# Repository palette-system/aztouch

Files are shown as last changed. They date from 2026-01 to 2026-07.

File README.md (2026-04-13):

# AZTOUCH (ミニトラックパッド)

<table><tr><td>
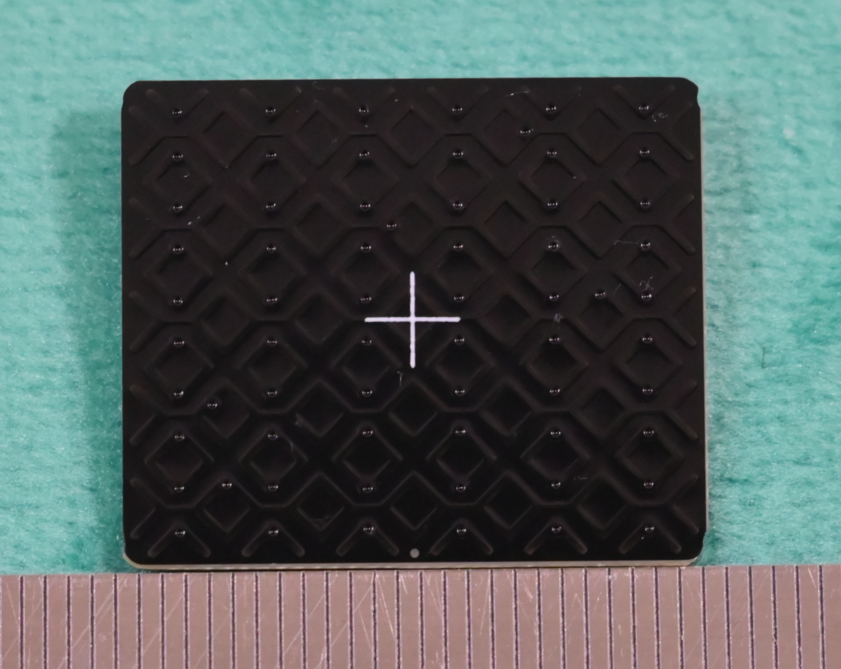
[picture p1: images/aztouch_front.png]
<br>
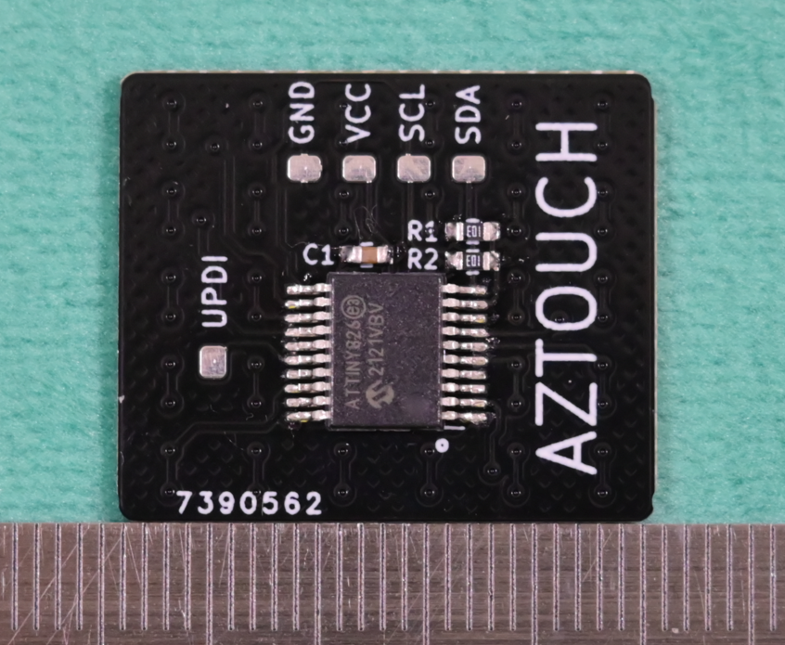
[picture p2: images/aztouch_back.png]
<br>
</td><td>
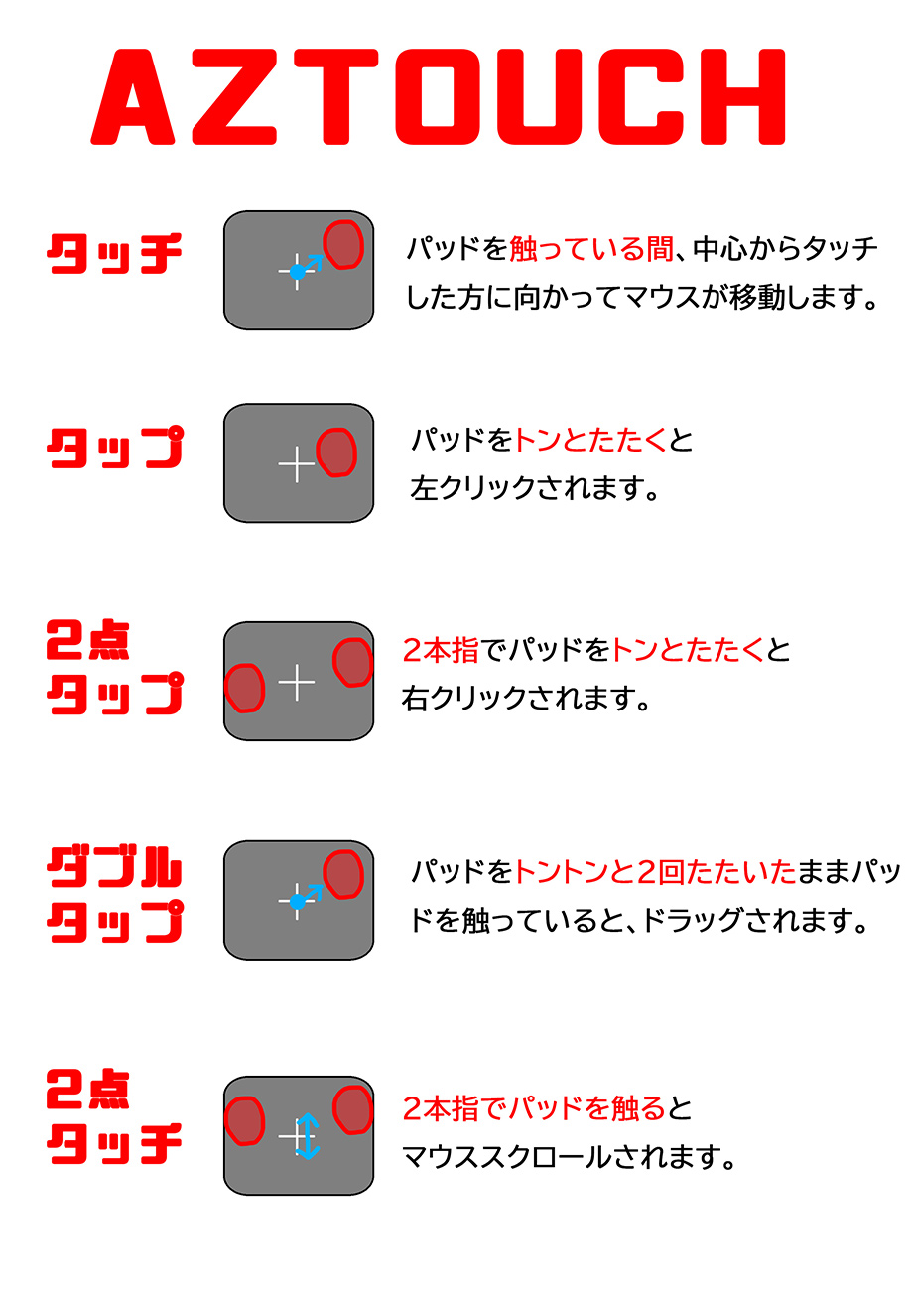
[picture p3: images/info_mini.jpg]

</td></tr></table>

<br><br>

## 接続方法

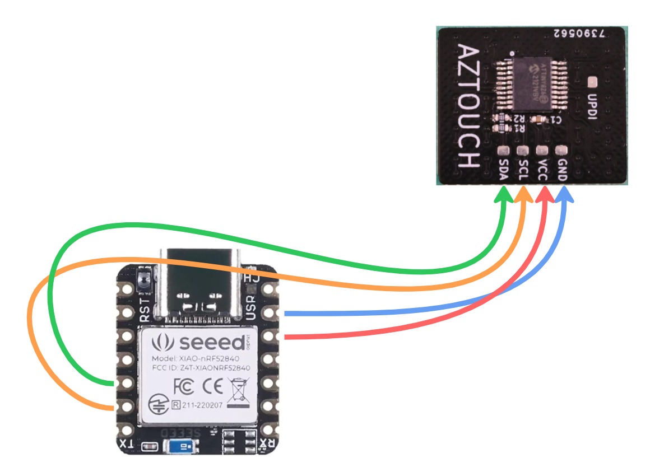
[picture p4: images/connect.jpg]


<br><br>

## 基本情報

<br>

電圧： 3V～5V<br>
消費電力： 1.7mA～2mA<br>
サイズ： 幅：25mm 高さ：21mm 厚さ：1mm<br>
I2Cアドレス：0x0A(固定)<br>

<br>
※ 電池駆動推薦、電源が安定しないと動作が不安定になる場合があります。<br>

<br><br>

## コマンド

<table>
  <tr>
    <th>コマンド</th>
    <th>内容</th>
  </tr>
  <tr>
    <td>0x30</td>
    <td>
    <b>設定値要求</b><br>
    このコマンドを送った次にデータリクエストが来た時に、1度だけ下記の7バイトのレスポンスになる。<br>
    [<br>
    　0x23(固定),<br>
    　マウススピード設定(0x00 ～ 0x04),<br>
    　drag_touch_time_max,<br>
    　drag_interval_time_max,<br>
    　tap_touch_time_max,<br>
    　move_touch_time_start,<br>
    　read_wait_time<br>
    ]<br>
    <br>
    コマンド例：[0x30]
    </td>
  </tr>
  <tr>
    <td>0x40</td>
    <td>
    <b>マウスのスピード設定</b><br>
    次に送られてきたバイトで移動速度を設定。<br>
    0x00 ～ 0x04 の間で設定可能<br>
    デフォルト値：0x02<br>
    <br>
    コマンド例：[0x40, 0x01]
    </td>
  </tr>
  <tr>
    <td>0x41</td>
    <td>
    <b>ドラッグ1回目のタッチの最大時間(n / 5ms)</b><br>
    次に送られてきたバイトで <b>drag_touch_time_max</b> の値を設定。<br>
    ※ 1=5ミリ秒、デフォルト値：0x64(500ミリ秒)<br>
    <br>
    コマンド例：[0x41, 0x64]
    </td>
  </tr>
  <tr>
    <td>0x42</td>
    <td>
    <b>ドラッグ2回目のタッチまでの最大時間(n / 5ms)</b><br>
    次に送られてきたバイトで <b>drag_interval_time_max</b> の値を設定。<br>
    ※ 1=5ミリ秒、デフォルト値：0x28(200ミリ秒)<br>
    <br>
    コマンド例：[0x42, 0x28]
    </td>
  </tr>
  <tr>
    <td>0x43</td>
    <td>
    <b>タップのタッチの最大時間(n / 5ms)</b><br>
    次に送られてきたバイトで <b>tap_touch_time_max</b> の値を設定。<br>
    ※ 1=5ミリ秒、デフォルト値：0x14(100ミリ秒)<br>
    <br>
    コマンド例：[0x43, 0x14]
    </td>
  </tr>
  <tr>
    <td>0x44</td>
    <td>
    <b>移動開始するまでの時間(n / 5ms)</b><br>
    次に送られてきたバイトで <b>move_touch_time_start</b> の値を設定。<br>
    ※ 1=5ミリ秒、デフォルト値：0x14(100ミリ秒)<br>
    <br>
    コマンド例：[0x44, 0x14]
    </td>
  </tr>
  <tr>
    <td>0x45</td>
    <td>
    <b>アナログ値取得待ち時間</b><br>
    次に送られてきたバイトで <b>read_wait_time</b> の値を設定。<br>
    ※ デフォルト値：0x28(40 NOP)<br>
    <br>
    コマンド例：[0x45, 0x28]
    </td>
  </tr>
  <tr>
    <td>0x4C</td>
    <td>
    <b>スリープ</b><br>
    AZTOUCHをスリープ状態にします。<br>
    スリープ状態の間消費電力は0.1mAになります。<br>
    I2Cのリクエストが飛ぶとスリープ状態から復帰します。<br>
    <br>
    コマンド例：[0x4C]
    </td>
  </tr>
</table>
※ EEPROM に保存されるため電源を落としても保持されます。<br>

<br><br>

## データレスポンス
AZ1UBALLやPIM447と同じフォーマットで操作情報を取得できます。<br>

<table>
  <tr>
    <th>バイト</th>
    <th>内容</th>
  </tr>
  <tr>
    <td>0x00</td>
    <td>左方向への移動距離</td>
  </tr>
  <tr>
    <td>0x01</td>
    <td>右方向への移動距離</td>
  </tr>
  <tr>
    <td>0x02</td>
    <td>上方向への移動距離</td>
  </tr>
  <tr>
    <td>0x03</td>
    <td>下方向への移動距離</td>
  </tr>
  <tr>
    <td>0x04</td>
    <td>タッチ情報<br>
    下記ビットを足し合わせた数値を返します。<br>
    <br>
    0x01 = 縦に2点タッチしている<br>
    0x02 = 横に2点タッチしている<br>
    0x04 = タッチしている<br>
    0x08 = ドラッグしている<br>
    0x10 = 未使用<br>
    0x20 = 未使用<br>
    0x40 = 2点タップ (右クリック)<br>
    0x80 = 1点タップ (左クリック)<br>
    </td>
  </tr>
</table>

<br><br>

## データ取得フロー
<br>
１．データリクエストを行ったタイミングでタッチ情報を取得するため、リードサイクルを少なくするほど省電力化できます。<br>
２．データリクエストの結果は前のサイクルのタイミングで取得したタッチ情報となります。<br>
３．タッチ情報取得のタイミングは割り込み禁止となるので、その間はI2Cのリクエストを受け取れません。<br>

<br>
<br>
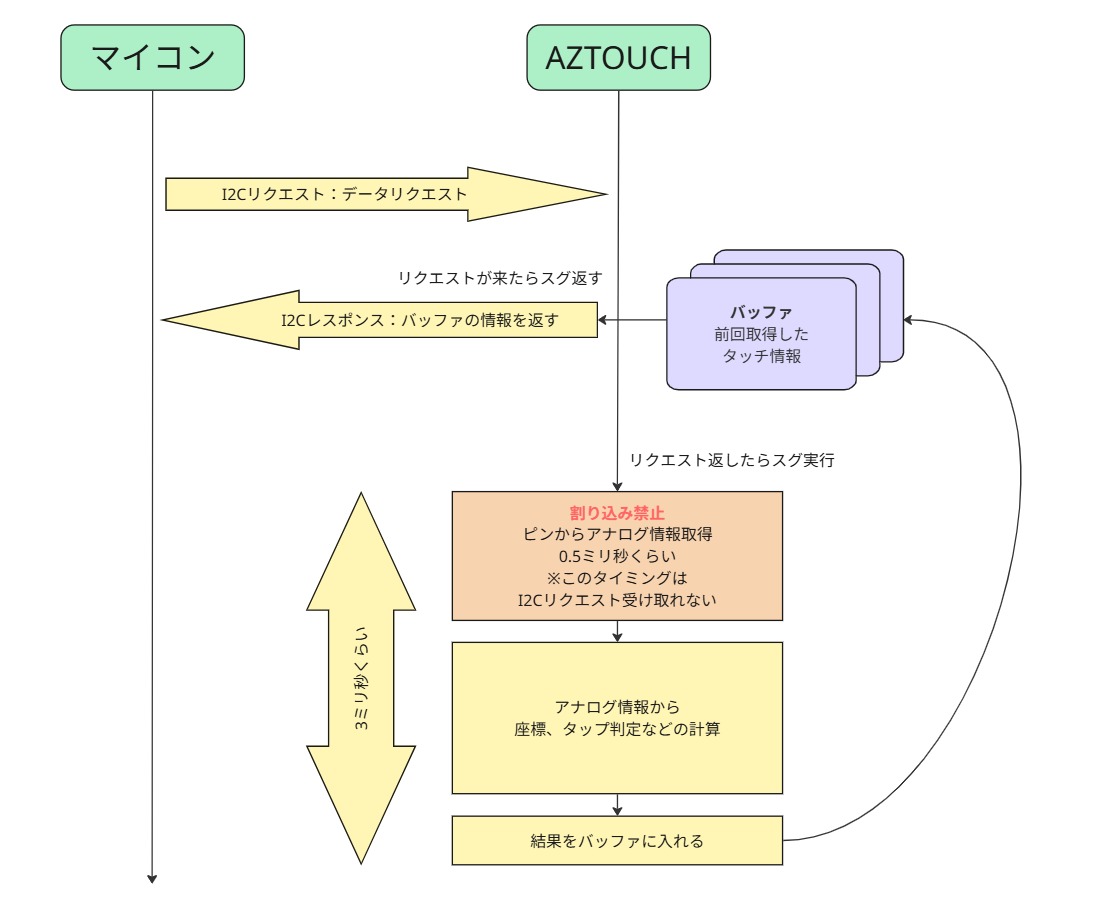
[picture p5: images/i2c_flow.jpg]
<br>

<br><br>

<b>サイクル間隔と各イベントの感度</b><br>
<table>
  <tr>
    <th>間隔(ミリ秒)</th>
    <th>消費電力(mA)</th>
    <th>移動</th>
    <th>2点タッチ</th>
    <th>タップ</th>
    <th>ダブルタップ</th>
  </tr>
  <tr>
    <td>10</td>
    <td>2.0</td>
    <td>〇</td>
    <td>〇</td>
    <td>〇</td>
    <td>〇</td>
  </tr>
  <tr>
    <td>20</td>
    <td>1.9</td>
    <td>〇</td>
    <td>〇</td>
    <td>〇</td>
    <td>△</td>
  </tr>
  <tr>
    <td>30</td>
    <td>1.8</td>
    <td>〇</td>
    <td>〇</td>
    <td>〇</td>
    <td>△</td>
  </tr>
  <tr>
    <td>40</td>
    <td>1.8</td>
    <td>〇</td>
    <td>〇</td>
    <td>△</td>
    <td>△</td>
  </tr>
  <tr>
    <td>50</td>
    <td>1.8</td>
    <td>〇</td>
    <td>〇</td>
    <td>△</td>
    <td>△</td>
  </tr>
  <tr>
    <td>60</td>
    <td>1.8</td>
    <td>〇</td>
    <td>〇</td>
    <td>△</td>
    <td>△</td>
  </tr>
  <tr>
    <td>70</td>
    <td>1.7</td>
    <td>〇</td>
    <td>〇</td>
    <td>×</td>
    <td>×</td>
  </tr>
  <tr>
    <td>80</td>
    <td>1.7</td>
    <td>△</td>
    <td>△</td>
    <td>×</td>
    <td>×</td>
  </tr>
  <tr>
    <td>90</td>
    <td>1.7</td>
    <td>△</td>
    <td>△</td>
    <td>×</td>
    <td>×</td>
  </tr>
  <tr>
    <td>100</td>
    <td>1.7</td>
    <td>△</td>
    <td>△</td>
    <td>×</td>
    <td>×</td>
  </tr>
</table>

<br><br>

## ピン情報取得フロー
<br>
１．割り込み禁止の間にタッチしているかどうかのアナログ値を取得します。<br>
２．読み込み時の待ち時間を <b>read_wait_time</b> で設定できます。<br>
<br>
<br>
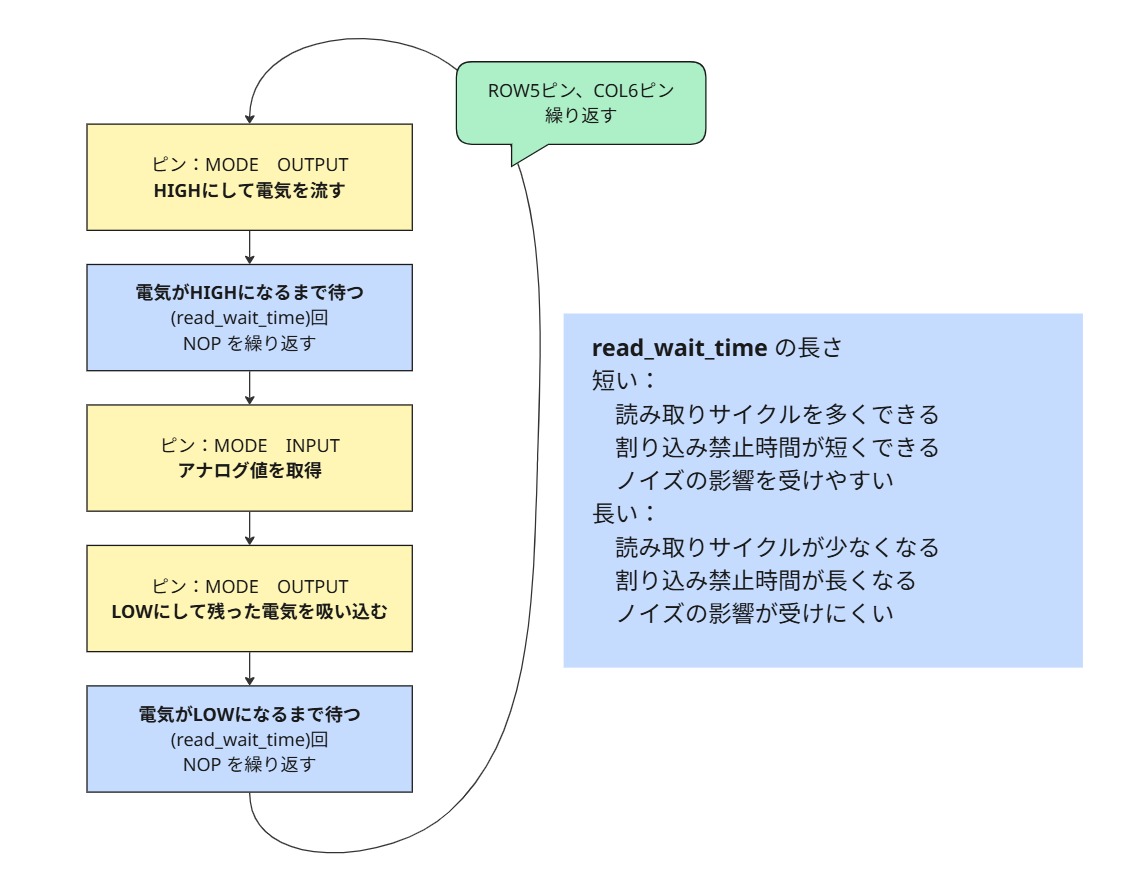
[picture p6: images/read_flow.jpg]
<br>

<br><br>

## アクション設定
<br>
<b>ドラッグ判定</b><br>
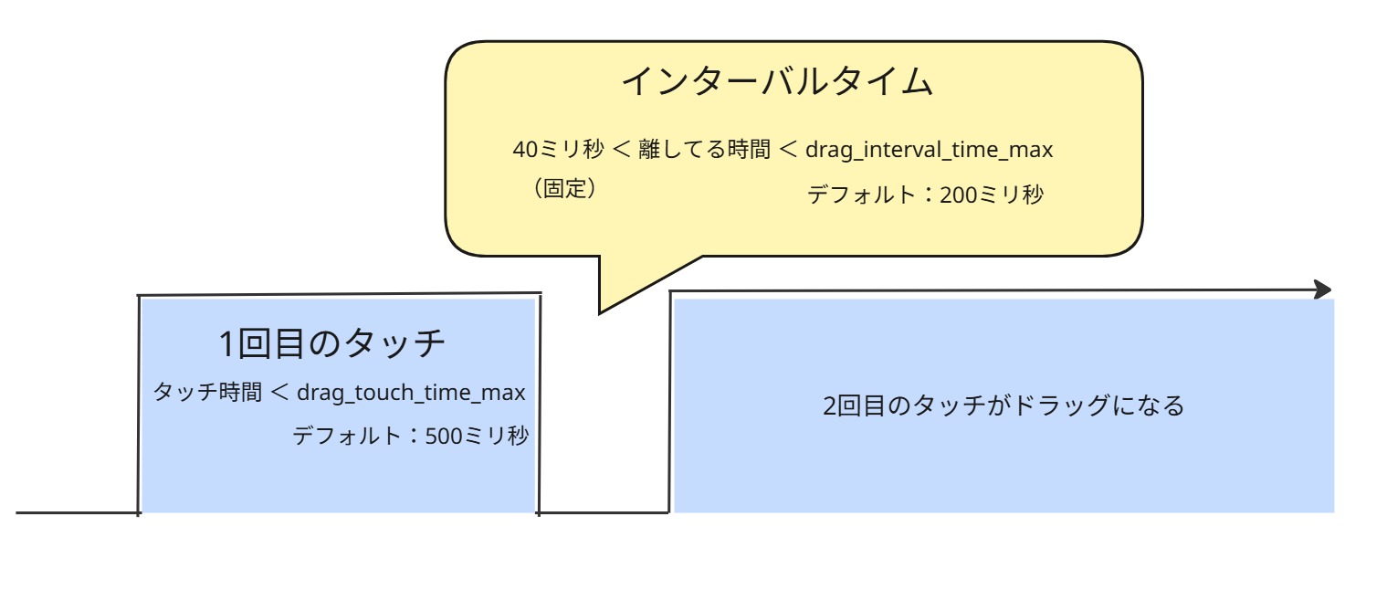
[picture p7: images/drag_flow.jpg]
<br>

<br>

<b>タップ判定</b><br>
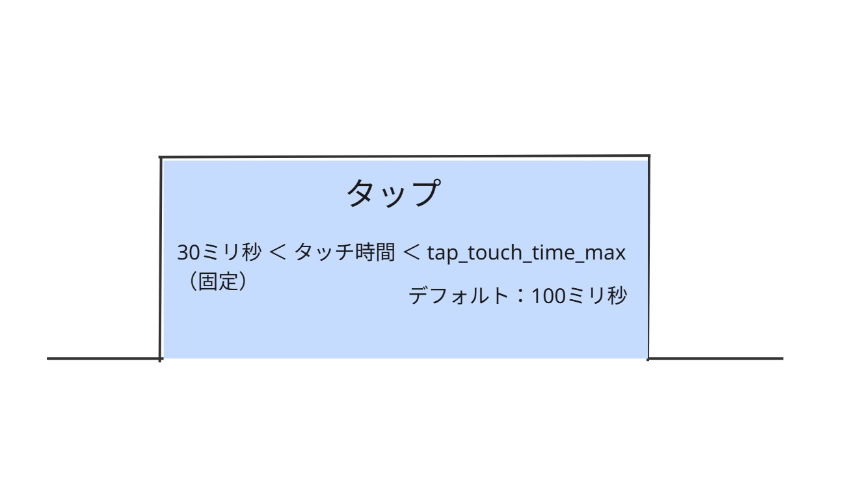
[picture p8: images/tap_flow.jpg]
<br>

<br>

<b>マウス移動判定</b><br>
タップの時にマウスが移動してしまわないように、タッチしてから少しの間マウス移動はしないようになっています。<br>
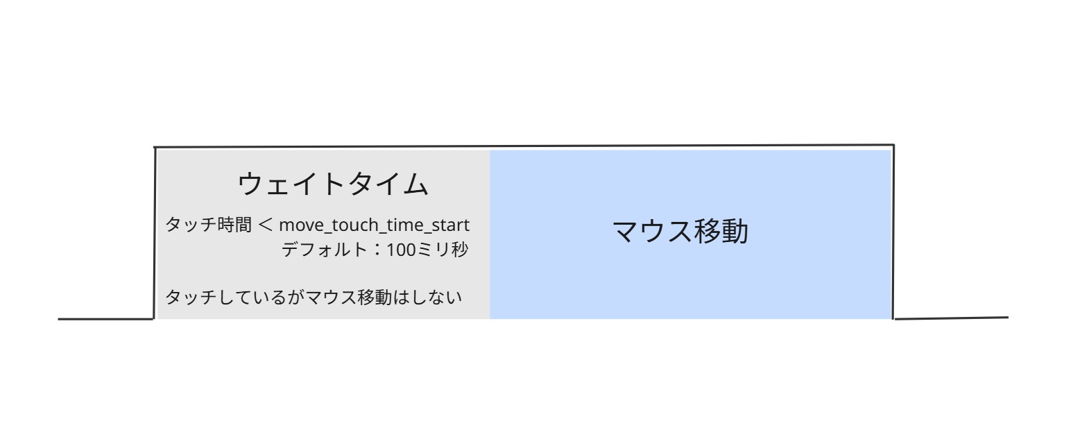
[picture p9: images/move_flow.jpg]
<br>

<br>

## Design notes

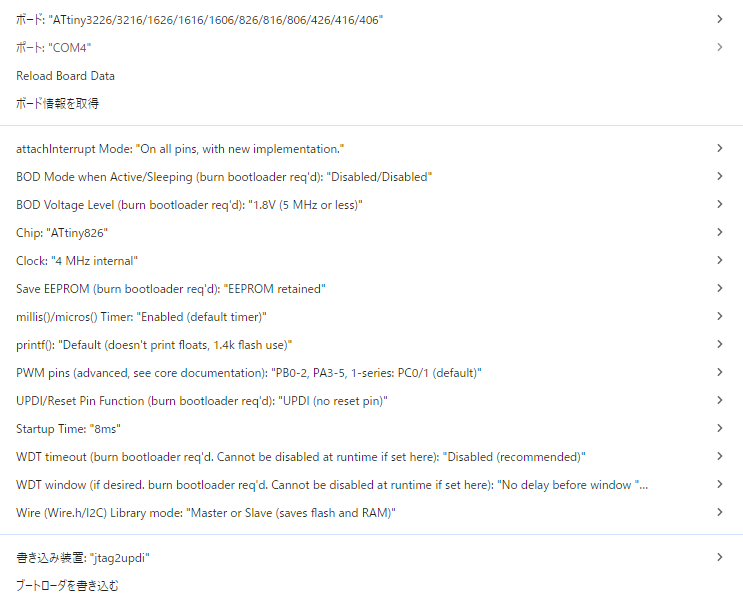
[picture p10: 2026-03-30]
firmware/aztouch_2/setting.png

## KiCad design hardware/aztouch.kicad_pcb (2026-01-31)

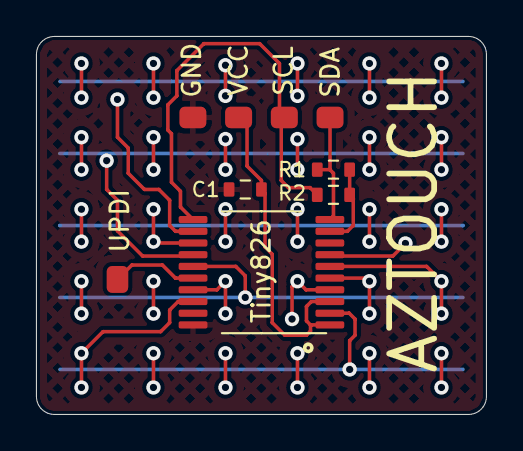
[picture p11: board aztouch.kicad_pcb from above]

Board: 2 copper layers, 25.0 x 21.0 mm, 4 parts (0 on the bottom side), 5 nets.

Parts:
C1: 1kΩ; R_0805_2012Metric1.2
R1, R2: 1kΩ; R_0805_2012Metric1.2
Tiny826: TSSOP-20_4.4x6.5mm_P0.65mm

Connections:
GND: C1.2, Tiny826.20
OUT1: R1.1, R2.1, Tiny826.9
SCL: R2.2, Tiny826.11
SDA: R1.2, Tiny826.10
VCC: C1.1, Tiny826.1, Tiny826.3

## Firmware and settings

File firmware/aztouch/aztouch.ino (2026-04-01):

// AZTOUCH パッド上のアナログ値を取得してI2Cに流す

// 開発環境の作り方
// https://ameblo.jp/pta55/entry-12654450554.html

#include <avr/pgmspace.h>
#include <avr/sleep.h>
#include <EEPROM.h>
#include <Wire.h>

// AZTOUCH のアドレス
#define I2C_SLAVE_ADD 0x0A

// I2C クロック数
#define I2C_CLOCK  100000

// EEPROM のアドレス
#define EEPADD_STATUS    0x00
#define EEPADD_SEND_TYPE    0x01
#define EEPADD_SPEED    0x02

// I2Cイベント
void receiveEvent(int data_len); // データを受け取った
void requestEvent(); // データ要求を受け取った


// 読み込んだパッドの数値
short read_org[11]; // 読み込んだアナログ値まま
short send_input[11]; // アナログ値から計算した入力値

// タッチしていない時のアナログ値
short pin_def[11];

// タッチした時の最大値(デフォルト値)
const short pin_max_def[11] = {106, 112, 110, 116, 103,  109, 97, 109, 108, 104, 104};


// 送信するデータのタイプ
short send_type;

// 読み込んだアナログ値の合計値
short read_total;

// 送信開始位置
short send_index;

// タッチしていた時間
unsigned long touch_start_time; // タッチ開始した時間
unsigned long touch_now_time; // 今の時間
unsigned long touch_last_time; // 最後にタッチした時間
unsigned long touch_time; // タッチし続けている時間

// タッチしていた時間内で2点タッチをどれくらいのサイクル行っていたか
short double_touch_flag;

// ドラッグ中かどうか(0x08=ドラッグ中)
uint8_t drag_flag;

// 前回測定した座標
short old_point[2];

// ピン設定
short all_pin[11] = {
  PIN_PC0, PIN_PC2, PIN_PB4, PIN_PC3, PIN_PA4, // row 5ピン
  PIN_PB5, PIN_PA7, PIN_PA6, PIN_PA1, PIN_PC1, PIN_PA2 // col 6ピン
};

// スピード設定
short speed_index;

// 速度設定用の構造体
struct speed_setting {
  short speed_x[21];
  short speed_y[17];
};

// 速度設定
const speed_setting speed_type[] = {
  {
    .speed_x = {8, 7, 6, 5, 4, 3, 2, 2, 1, 0, 0, 1, 2, 2, 3, 4, 5, 6, 7, 8, 8},
    .speed_y = {7, 6, 5, 4, 3, 2, 1, 0, 0, 1, 2, 3, 4, 5, 6, 7, 7}
  },
  {
    .speed_x = {9, 8, 7, 6, 5, 4, 3, 2, 1, 0, 0, 1, 2, 3, 4, 5, 6, 7, 8, 9, 9},
    .speed_y = {7, 6, 5, 4, 3, 2, 1, 0, 0, 1, 2, 3, 4, 5, 6, 7, 7}
  },
  {
    .speed_x = {10, 9, 8, 7, 6, 5, 4, 3, 2, 0, 0, 2, 3, 4, 5, 6, 7, 8, 9, 10, 10},
    .speed_y = {10, 8, 6, 5, 4, 3, 2, 0, 0, 2, 3, 4, 5, 6, 8, 10, 10}
  },
  {
    .speed_x = {12, 10, 8, 7, 6, 5, 4, 3, 2, 0, 0, 2, 3, 4, 5, 6, 7, 8, 10, 12, 12},
    .speed_y = {12, 10, 8, 6, 4, 3, 2, 0, 0, 2, 3, 4, 6, 8, 10, 12, 12}
  },
  {
    .speed_x = {14, 12, 10, 7, 6, 5, 4, 3, 2, 0, 0, 2, 3, 4, 5, 6, 7, 10, 12, 14, 14},
    .speed_y = {14, 12, 10, 6, 4, 3, 2, 0, 0, 2, 3, 4, 6, 10, 12, 14, 14}
  }
};

// 現在の速度設定
speed_setting speed_buf = {
  .speed_x = {8, 7, 6, 5, 4, 3, 2, 2, 1, 0, 0, 1, 2, 2, 3, 4, 5, 6, 7, 8, 8},
  .speed_y = {7, 6, 5, 4, 3, 2, 1, 0, 0, 1, 2, 3, 4, 5, 6, 7, 7}
};

// スリープフラグ
short sleep_flag;

// タッチのアナログ値取得
void read_analog() {
  short i;
  noInterrupts(); // 割り込み禁止 開始
  for (i=0; i<11; i++) {
    // 読み取りピンをHIGHにして電気を流す
    pinMode(all_pin[i], OUTPUT);
    digitalWrite(all_pin[i], 1);
    delayMicroseconds(10);
    // 読み取りピンのアナログ値を取得
    pinMode(all_pin[i], INPUT);
    read_org[i] = analogRead(all_pin[i]);
    // 読み取りピンをLOWにして残った電気を吸い取る
    pinMode(all_pin[i], OUTPUT);
    digitalWrite(all_pin[i], 0);
    delayMicroseconds(10);
  }
  interrupts(); // 割り込み禁止 解除
}

// タッチの情報を取得
void read_touch() {
  short i;
  read_total = 0;
  // タッチのアナログ値取得
  read_analog();
  // ピンごとのタッチ最大値からのタッチ割合を計算
  for (i=0; i<11; i++) {
    send_input[i] = ((read_org[i] - pin_def[i]) * 128) / pin_max_def[i];
    read_total += read_org[i] - pin_def[i];
  }
  if (read_total > 1023) {
    read_total = 1023;
  } else if (read_total < 0) {
    read_total = 0;
  }
  // 起動してすぐのアナログ値を保持してこれをデフォルト値にする
  if (send_index == 3) {
    for (i=0; i<11; i++) {
      pin_def[i] = read_org[i];
    }
  }
  send_index++;
}

// I2C コマンドを受け取った
void receiveEvent(int data_len) {
  short t;
  // コマンド受け取り
  if (Wire.available()) {
    t = Wire.read();
    if (t >= 0x20 && t <= 0x23) {
      // 0x20 : AZ1UBALL と同じレスポンス
      // 0x21 : AZTOUCH 2バイトレスポンス
      // 0x22 : タッチのX,Y座標を返す
      // 0x23 : row,colピンのアナログ値をそのまま返す
      if ((t & 0x0F) != send_type) {
        send_type = (t & 0x0F);
        EEPROM.write(EEPADD_SEND_TYPE, (t & 0x0F));
      }
    } else if (t >= 0x30 && t <= 0x34) {
      // 0x30 ～ 0x34 速度設定
      if ((t & 0x0F) != speed_index) {
        speed_index = (t & 0x0F);
        EEPROM.write(EEPADD_SPEED, (speed_index & 0x0F));
        memcpy(&speed_buf, &speed_type[speed_index], sizeof(speed_setting));
      }
    } else if (t == 0x40) {
      // スリープ実行フラグON
      sleep_flag = 1;
    }
  }
}

// I2C データ要求を受け取った時の処理
void requestEvent() {
  short c[11], i, r[2], e, tx, ty, tf, x, y;
  unsigned long t;

  // 送信バッファ
  uint8_t send_buf[24];

  if (send_type == 3) { // type 2. row,colピンのアナログ値をそのまま返す
    // ピン情報を取得
    read_touch();
    // ピンのアナログ値をそのまま返す
    for (i=0; i<11; i++) {
      send_buf[(i*2)] = (read_org[i] >> 8) & 0xFF;
      send_buf[(i*2) + 1] = read_org[i] & 0xFF;
    }
    Wire.write(send_buf, 22);
    return;

  }

  // ピン情報を取得
  read_touch();

  // ピン情報からサーモを作成
  // これをした方がカーソルのブレが少なかった
  for (i=0; i<11; i++) {
    if (send_input[i] > 5) {
      // 該当ピンがタッチされている
      if (i == 0 || i == 5) {
        // 前のピンが無い
        c[i] = ((send_input[i] * 128) / (send_input[i] + send_input[i + 1])); // 次ピン との割合
      } else if (i == 4 || i == 10) {
        // 次のピンが無い
        c[i] = ((send_input[i] * 128) / (send_input[i] + send_input[i - 1])); // 前ピン との割合
      } else {
        // 前後のピンがある
        c[i] = ((send_input[i] * 128) / (send_input[i] + send_input[i - 1] + send_input[i + 1])); // 前後ピン との割合
      }
    } else {
      // 該当ピンがタッチされていない
      c[i] = 0;
    }
  }

  // サーモを元にタッチ座標を計算
  r[0] = 0;
  for (i=0; i<5; i++) {
    if (i < 2 && c[i] > 0 && c[i+1] > 0 && c[i+3] > 0) { // 4点
      r[0] = (i * 128) + ((c[i+3] * 384) / (c[i] + c[i+3]));
      i += 3;
    } else if (i < 3 && c[i] > 0 && c[i+1] > 0 && c[i+2] > 0) { // 3点
      r[0] = (i * 128) + ((c[i+2] * 256) / (c[i] + c[i+2]));
      i += 2;
    } else if (i < 4 && c[i] > 0 && c[i+1] > 0) { // 2点
      r[0] = (i * 128) + ((c[i+1] * 128) / (c[i] + c[i+1]));
      i += 1;
    } else if (c[i] > 0) { // 1点
      r[0] = i * 128;
    }
  }
  r[1] = 0;
  for (i=0; i<6; i++) {
    e = i + 5;
    if (e < 9 && c[e] > 0 && c[e+1] > 0 && c[e+2] > 0) { // 3点
      r[1] = (i * 128) + ((c[e+2] * 256) / (c[e] + c[e+2]));
      i += 2;
    } else if (i < 10 && c[e] > 0 && c[e+1] > 0) { // 2点
      r[1] = (i * 128) + ((c[e+1] * 128) / (c[e] + c[e+1]));
      i += 1;
    } else if (c[e] > 0) { // 1点
      r[1] = i * 128;
    }
  }

  // 2点タッチを判定
  tf = 0;
  ty = 0; // 3になったら2点タッチ
  tx = 0; // 3になったら2点タッチ
  if (read_total > 60) {
    for (i=0; i<5; i++) {
      if (ty==0 && c[i] > 10) { // 1つタッチを見つけた
        ty++;
      } else if (ty == 1 && c[i] == 0) { // 触ってない場所を見つけた
        ty++;
      } else if (ty == 2 && c[i] > 10) { // 2つ目タッチを見つけた
        ty++;
        double_touch_flag++; // タッチ中に2点タッチがあったかどうか
        tf |= 0x01; // 現在2点タッチかどうか
      }
    }
    for (i=5; i<11; i++) {
      if (tx==0 && c[i] > 10) { // 1つタッチを見つけた
        tx++;
      } else if (tx == 1 && c[i] == 0) { // 触ってない場所を見つけた
        tx++;
      } else if (tx == 2 && c[i] > 10) { // 2つ目タッチを見つけた
        tx++;
        double_touch_flag++; // タッチ中に2点タッチがあったかどうか
        tf |= 0x02; // 現在2点タッチかどうか
      }
    }
  }

  // タッチ操作フラグ
  touch_now_time = millis();
  if (read_total > 60) {
    // タッチしはじめ
    if (old_point[0] == 0 && old_point[1] == 0) {
      touch_start_time = touch_now_time; // タッチ開始時間を設定
      t = touch_now_time - touch_last_time; // 前のタッチからどれくらい時間が経ったか
      if (t > 40 && t < 160 && touch_time < 500) drag_flag = 0x08; // 前のタッチからすぐタッチされた & 前のタッチ時間が短い ならドラッグ
    }
    touch_time = touch_now_time - touch_start_time; // タッチされ続けている時間 ミリ秒
    touch_last_time = touch_now_time; // 最後にタッチした時間
    tf |= 0x04 | drag_flag; // タッチ中 + ドラッグ中

  } else {
    // 離された && タッチ時間が短ければタップと判定
    if (old_point[0] > 0 && old_point[1] > 0 && touch_time > 30 && touch_time < 100) { // タップ判定(前測定時タッチされていた＋タッチ時間が短い)
      if (double_touch_flag > 2) {
        // 2点でタップ
        tf |= 0x40;
      } else {
        // 1点でタップ
        tf |= 0x80;
      }
    }
    // フラグリセット
    double_touch_flag = 0; // タッチ中に2点タッチになった事があったか
    touch_start_time = 0; // タッチ開始時間
    drag_flag = 0; // ドラッグ中
  }

  if (send_type == 2) {
    // タッチのX,Y座標を返す
    send_buf[0] = (r[1] >> 8) & 0xFF; // x
    send_buf[1] = r[1] & 0xFF; // x
    send_buf[2] = (r[0] >> 8) & 0xFF; // y
    send_buf[3] = r[0] & 0xFF; // y
    send_buf[4] = (read_total >> 2) & 0xFF; // タッチ量
    send_buf[5] = tf; // タッチ操作フラグ
    Wire.write(send_buf, 6);

  } else if (send_type == 1) {
    // 1 = 2バイトレスポンス
    send_buf[0] = 0; // y 4bit | x 4bit
    send_buf[1] = tf; // タッチ操作フラグ
    if (read_total > 60 && touch_time > 100 && old_point[0] > 0 && old_point[1] > 0) { // タッチされている & タッチしてから0.1秒以上 & 前回のタッチ座標がある
      x = (r[1] / 32);
      y = (r[0] / 32);
      if (!(tf & 0x02)) {
        // 横移動
        send_buf[0] |= speed_buf.speed_x[x] & 0x0F;
      }
      if (!(tf & 0x01)) {
        // 縦移動
        send_buf[0] |= (speed_buf.speed_y[y] << 4) & 0xF0;
      }
      if (x < 10) send_buf[1] |= 0x10; // X移動マイナスフラグ
      if (y < 8) send_buf[1] |= 0x20; // Y移動マイナスフラグ
    }
    Wire.write(send_buf, 2);

  } else {
    // 0 = デフォルト az1uballと同じフォーマットを返す
    if (read_total > 60 && touch_time > 100 && old_point[0] > 0 && old_point[1] > 0) { // タッチされている & タッチしてから0.1秒以上 & 前回のタッチ座標がある
      x = (r[1] / 32);
      y = (r[0] / 32);
      if (tf & 0x02) {
        // 横に2点タッチされていた場合は縦移動しない
        send_buf[0] = 0;
        send_buf[1] = 0;
      } else {
        // 横移動
        if (x > 10) {
          send_buf[0] = 0;
          send_buf[1] = speed_buf.speed_x[x];
        } else {
          send_buf[0] = speed_buf.speed_x[x];
          send_buf[1] = 0;
        }
      }
      if (tf & 0x01) {
        // 縦に2点タッチされていた場合は縦移動しない
        send_buf[2] = 0;
        send_buf[3] = 0;
      } else {
        // 縦移動
        if (y > 8) {
          send_buf[2] = 0;
          send_buf[3] = speed_buf.speed_y[y];
        } else {
          send_buf[2] = speed_buf.speed_y[y];
          send_buf[3] = 0;
        }
      }
    } else {
      send_buf[0] = 0;
      send_buf[1] = 0;
      send_buf[2] = 0;
      send_buf[3] = 0;
    }
    send_buf[4] = tf; // タッチ操作フラグ
    Wire.write(send_buf, 5);
  }

  if (read_total > 60) {
    // 前回の位置を保持
    old_point[0] = r[0];
    old_point[1] = r[1];
  } else {
    // タッチしていない
    old_point[0] = 0;
    old_point[1] = 0;
  }
  sleep_flag = 1;
}

void setup() {
  uint8_t c;
  short i;

  // VCCチェックピン HIGHT
  pinMode(PIN_PA5, OUTPUT);
  digitalWrite(PIN_PA5, 1);
  delay(10);

  // I2C ピンプルアップ
  pinMode(PIN_PB2, OUTPUT);
  digitalWrite(PIN_PB2, 1);
  delay(10);

  // 初めての起動の場合EPPROMにタッチ最大値設定を書き込む
  c = EEPROM.read(EEPADD_STATUS); // 最初の0バイト目を読み込む
  if (c != 0x21) {
    EEPROM.write(EEPADD_STATUS, 0x21); // 初期化したよを書き込む
    EEPROM.write(EEPADD_SEND_TYPE, 0x00); // レスポンスタイプAZ1UBALLフォーマットを指定
    EEPROM.write(EEPADD_SPEED, 0x03); // カーソル移動速度を指定
  }

  // レスポンスタイプをEPPROMから読み込む
  send_type = EEPROM.read(EEPADD_SEND_TYPE);

  // カーソルの移動速度をEPPROMから読み込む
  speed_index = EEPROM.read(EEPADD_SPEED);
  memcpy(&speed_buf, &speed_type[speed_index], sizeof(speed_setting));

  // センサーピン初期化
  // col : A4, A5, A6, A7, B5 
  // row : C0, C1, C2, C3, A1, A2 (10K)
  for (i=0; i<11; i++) {
    pinMode(all_pin[i], OUTPUT);
    digitalWrite(all_pin[i], 0);
    pin_def[i] = 0;
  }
  delay(10);

  // スリープ初期化
  set_sleep_mode(SLEEP_MODE_PWR_DOWN);
  sleep_enable();

  // I2C スレーブ初期化
  Wire.begin(I2C_SLAVE_ADD); // アドレス
  Wire.setClock(I2C_CLOCK); // クロック数
  Wire.onReceive(receiveEvent);
  Wire.onRequest(requestEvent);

  send_index = 0;
  double_touch_flag = 0;
  drag_flag = 0;
  sleep_flag = 0;

}


void loop() {
  // デフォルト値を取得するため起動してから5回だけパッド情報取得
  if (send_index < 5) read_touch();

  // スリープ実行
  if (sleep_flag) {
    sleep_flag = 0;
    sleep_cpu();
  }

  delay(100);
}

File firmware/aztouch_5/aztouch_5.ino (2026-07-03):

// AZTOUCH パッド上のアナログ値を取得してI2Cに流す

// 開発環境の作り方
// https://ameblo.jp/pta55/entry-12654450554.html

#include <avr/pgmspace.h>
#include <avr/sleep.h>
#include <avr/io.h>
#include <avr/cpufunc.h>
#include <avr/interrupt.h>
// #include <EEPROM.h>
#include <Wire.h>

// AZTOUCH のアドレス
#define I2C_SLAVE_ADD 0x0A

// I2C クロック数
#define I2C_CLOCK  100000

// EEPROM のアドレス
#define EEPADD_STATUS              0x00
#define EEPADD_SPEED               0x01
#define EEPADD_DRAG_TOUCH_TIME     0x02
#define EEPADD_DRAG_INTERVAL_TIME  0x03
#define EEPADD_TAP_TOUCH_TIME      0x04
#define EEPADD_MOVE_START_TIME     0x05
#define EEPADD_READ_WAIT_TIME      0x06

// I2Cイベント
void receiveEvent(int data_len); // データを受け取った
void requestEvent(); // データ要求を受け取った




// 9四方
short read_pin[9] = {PIN_PB4, PIN_PC0, PIN_PC1,  PIN_PB5, PIN_PC3, PIN_PC2,  PIN_PA7, PIN_PA1, PIN_PA2};
// short pin_wrk[9] = {114, 114, 130, 125, 124, 124, 101, 118, 119};
short pin_wrk[9] = {113, 115, 115,  124, 122, 125,  104, 122, 125};
// short pin_min[9] = {622, 638, 599, 606, 622, 607, 640, 609, 594};
short pin_min[9] = {617, 628, 617,  600, 599, 599,  637, 603, 588};
// short pin_max[9] = {736, 752, 729, 731, 746, 731, 741, 727, 713};
short pin_max[9] = {730, 743, 732,  724, 721, 724,  741, 725, 713};
short xy_old[5][3] = {{0,0,0}, {0,0,0}, {0,0,0}, {0,0,0}, {0,0,0}};


// 送信バッファ
uint8_t send_buf[24];




uint16_t millis_my() {
  while (RTC.STATUS & RTC_CNTBUSY_bm);
  return RTC.CNT;
}







// I2C コマンドを受け取った
void receiveEvent(int data_len) {
  // コマンド受け取り
  while (Wire.available()) {
    Wire.read();
  }
}


short xl, xc, xr,  yt, ym, yb, tp;
short xl_p, xr_p, yt_p, yb_p;
short x, y;
short p[9];
short r[9];
short ch_i, ch_x, ch_y, mv_x, mv_y;
short rx, ry;

// I2C データ要求を受け取った時の処理
void requestEvent() {
  short i, t, rp;

  noInterrupts(); // 割り込み禁止 開始
  for (i=0; i<9; i++) {
    rp = read_pin[i];
    pinMode(rp, OUTPUT);
    digitalWrite(rp, 1);
    for (t=0; t<80; t++) _NOP();
    pinMode(rp, INPUT);
    for (t=0; t<80; t++) _NOP();
    r[i] = analogRead(rp);
    pinMode(rp, OUTPUT);
    digitalWrite(rp, 0);
  }
  interrupts(); // 割り込み禁止 解除
  for (i=0; i<9; i++) {
    if (r[i] < pin_min[i]) r[i] = pin_min[i];
    if (r[i] > pin_max[i]) r[i] = pin_max[i];
    p[i] = (r[i] - pin_min[i]) * 128 / pin_wrk[i];
  }
  xl = p[0] + p[3] + p[6];
  xc = p[1] + p[4] + p[7];
  xr = p[2] + p[5] + p[8];

  yt = p[0] + p[1] + p[2];
  ym = p[3] + p[4] + p[5];
  yb = p[6] + p[7] + p[8];


  if ((xc + xl) < 100 || (xc + xr) < 100 || (yt + ym) < 100 || (yb + ym) < 100) {
    x = 0;
    y = 0;
    tp = 0;
  } else {
    xl_p = (xl * 128) / (xc + xl);
    xr_p = (xr * 128) / (xc + xr);
    x = xr_p - xl_p;

    yt_p = (yt * 128) / (ym + yt);
    yb_p = (yb * 128) / (ym + yb);
    y = yb_p - yt_p;

    tp = yt + ym + yb;
  }

  if (tp < 120) {
    x = 0;
    y = 0;
    tp = 0;
  }

  for (i=0; i<4; i++) {
    xy_old[i][0] = xy_old[i + 1][0];
    xy_old[i][1] = xy_old[i + 1][1];
    xy_old[i][2] = xy_old[i + 1][2];
  }
  xy_old[4][0] = x;
  xy_old[4][1] = y;
  xy_old[4][2] = tp;

  ch_i = mv_x = mv_y = 0;
  for (i=0; i<5; i++) {
    if (xy_old[i][2] > 120) {
      if (ch_i > 0 && xy_old[i - 1][2] > 120 && xy_old[i][2] > 120) {
        ch_x = xy_old[i][0] - xy_old[i - 1][0];
        ch_y = xy_old[i][1] - xy_old[i - 1][1];
        if (ch_x > -200 && ch_y > -200 && ch_x < 200 && ch_y < 200
            // && !((ch_x > -2 && ch_x < 2) || (ch_y > -2 && ch_y < 2))
            ) {
              mv_x += ch_x;
              mv_y += ch_y;
        }
      }
      ch_i++;
    } else {
      ch_i = 0;
    }
  }
  rx = mv_x / 3;
  ry = mv_y / 3;

  if (rx < 0) {
    send_buf[0] = abs(rx);
    send_buf[1] = 0;
  } else {
    send_buf[0] = 0;
    send_buf[1] = rx;
  }
  if (ry < 0) {
    send_buf[2] = abs(ry);
    send_buf[3] = 0;
  } else {
    send_buf[2] = 0;
    send_buf[3] = ry;
  }
  send_buf[4] = 0;
  Wire.write(send_buf, 5);

/*
  send_buf[0] = (r[0] >> 8) & 0xFF;
  send_buf[1] = r[0] & 0xFF;
  send_buf[2] = (r[1] >> 8) & 0xFF;
  send_buf[3] = r[1] & 0xFF;
  send_buf[4] = (r[2] >> 8) & 0xFF;
  send_buf[5] = r[2] & 0xFF;
  send_buf[6] = (r[3] >> 8) & 0xFF;
  send_buf[7] = r[3] & 0xFF;
  send_buf[8] = (r[4] >> 8) & 0xFF;
  send_buf[9] = r[4] & 0xFF;
  send_buf[10] = (r[5] >> 8) & 0xFF;
  send_buf[11] = r[5] & 0xFF;
  send_buf[12] = (r[6] >> 8) & 0xFF;
  send_buf[13] = r[6] & 0xFF;
  send_buf[14] = (r[7] >> 8) & 0xFF;
  send_buf[15] = r[7] & 0xFF;
  send_buf[16] = (r[8] >> 8) & 0xFF;
  send_buf[17] = r[8] & 0xFF;
  Wire.write(send_buf, 18);
*/

}

void setup() {
  short i;



  // センサーピン初期化
  for (i=0; i<9; i++) {
    pinMode(read_pin[i], OUTPUT);
    digitalWrite(read_pin[i], 0);
  }
  delay(10);

  // I2C スレーブ初期化
  Wire.begin(I2C_SLAVE_ADD); // アドレス
  Wire.setClock(I2C_CLOCK); // クロック数
  Wire.onReceive(receiveEvent);
  Wire.onRequest(requestEvent);


}


void loop() {

}

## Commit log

2026-01-31 add kicad data
    [aztouch.kicad_pcb]
2026-04-02 update flow image
